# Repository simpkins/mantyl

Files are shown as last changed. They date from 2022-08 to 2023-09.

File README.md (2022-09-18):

# Mantyl: concave split keyboard

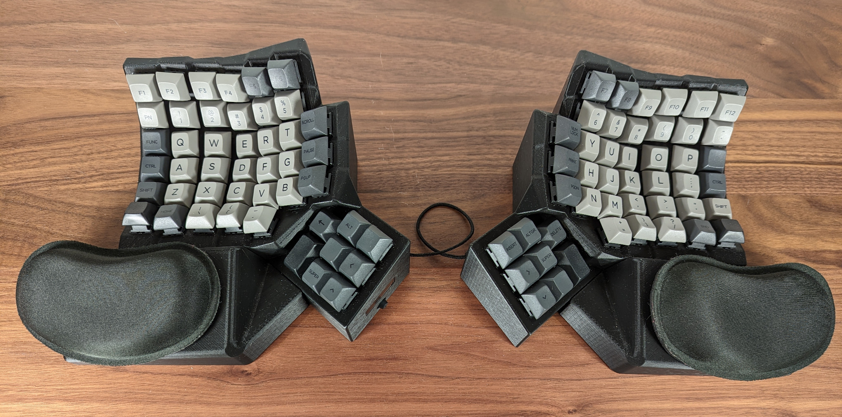
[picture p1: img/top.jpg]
Keyboard Image


This repository contains the CAD design code and firmware for my custom
keyboard.

# Keyboard Model

The `cad` directory contains code for generating the keyboard model, using
Python scripts for [Blender](https://www.blender.org/).

# Firmware

The `src` directory contains the firmware for the keyboard.  I use a
[FeatherS3](https://esp32s3.com/feathers3.html) for the microcontroller,
and the firmware code is built with the
[ESP-IDF](https://github.com/espressif/esp-idf).

# Gallery

Some more images can be found in the [img](img) directory.

# Documentation

The [doc](doc) directory contains various documentation.  The
[assembly.md](doc/assembly.md) and [wiring.md](doc/wiring.md) files may be of
interest if you are looking to print and assemble your own version of the
keyboard.

# Inspiration

I've used [Maltron](https://www.maltron.com/) keyboards for quite a long time.
My original Maltron keyboard was a PS/2 model, and back in 2013 I built my own
[keyboard controller](https://github.com/simpkins/avrpp) for it using a
[Teensy++ 2.0](https://www.pjrc.com/store/teensypp.html) microcontroller, in
order to convert it to a USB keyboard.

The layout for this keyboard is heavily influenced by the Maltron layout--I
wanted it to be fairly similar since I've used the Maltron layout for so long.

For generating the keyboard model programmatically I took some inspiration from
the [Dactyl-Manuform](https://github.com/abstracthat/dactyl-manuform) keyboard.
I initially started out using OpenSCAD, but quickly found it fairly limiting
and switched to using Python APIs for blender.  For some choices of the
electronic components, particularly the SX1509, I relied on some of the
component selection from my co-worker Wez's
[Halfdeck](https://github.com/wez/halfdeck) keyboard.

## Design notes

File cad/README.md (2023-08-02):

# Running the Mesh Generation Code

This code requires Blender 3.4+.

## Generating STL Files

The `generate_stl.py` file will export STL files for all of the keyboard parts.
It will place them inside an `_out/` directory.

This script can be run from the command line as follows:

```
blender -b -P generate_stl.py
```

## Development

If you want to make changes to the CAD logic, using the `test.py` script is the
easiest way to do this.

You can start it from the command line as follows:

```
blender -P test.py
```

This will launch blender and run the code from
[`mantyl/testing.py`](mantyl/testing.py).  Whenever
any of the source code files are updated it will reload and re-run the code to
redisplay the generated objects.

This makes it easy to edit the Python source code and have blender
automatically redisplay changes each time you save any of the files.

The logic for monitoring source code changes is in
[`mantyl/auto_update.py`](mantyl/auto_update.py).

# Checking for Errors

Blender's boolean operators can occasionally generate bad geometry.  This
sometimes happens if the operation generates new vertices at the mesh
intersection points that are very close to existing vertices.  This can result
in faces that intersect, which may cause problems when attempting to slice the
model for 3D printing.

The easiest way to detect this problem is with Blender's
[3D Print Toolbox](https://docs.blender.org/manual/en/latest/addons/mesh/3d_print_toolbox.html).
Enable the toolbox in the Add-On preferences.  After enabling it, press `N` in
an 3D view area to show the sidebar, and a "3D-Print" tab will be available.
This tab has buttons to check for intersections, and can highlight intersecting
faces.

# Other Notes

## Units

My scripts are written with the units in millimeters.  Historically this was
because I initially developed the keyboard model in OpenSCAD rather than
Blender, which uses units in millimeters rather than meters.

However, using millimeters works nicely in practice for Blender too: this
avoids having to scale the units by 1000 when exporting to an STL file, as 3D
print software generally assumes the STL units are in millimeters, while
Blender emits the units as meters by default.

## OpenSCAD

I initially attempted to build the keyboard model using OpenSCAD.  However, it
unfortunately has many more problems than Blender with generating bad geometry
after performing hull, union, and difference operations on objects in arbitrary
locations.  These problems unfortunately typically don't manifest themselves
until after you generate an STL file and attempt to slice it for 3D printing.
With OpenSCAD it was also much harder to detect which faces / facets were
problematic.

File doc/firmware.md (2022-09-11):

The firmware requires the ESP-IDF to build.  During development I have been
using the latest github master branch, which is currently in beta for the v5.0
release.

# eFuse Settings

The `USB_PHY_SEL` eFuse needs to be burned in order to have the device behave
purely as a USB keyboard.  Without this setting when the chip powers on it
first enables the USB Serial/JTAG functionality, and will enumerate as a USB
serial device before it fully boots and changes configuration to a USB HID
device.  This behavior can be undesirable in many circumstances, so burning the
`USB_PHY_SEL` eFuse is recommended.  e.g., when plugged into the keyboard port
of USB KVM switches, some KVM switches will power cycle the port if anything
other than a keyboard is plugged in.

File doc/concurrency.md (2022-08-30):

Some notes on tasks and concurrency in the firmware:

# Tasks

- main task
  All I2C communication is performed from this task.  This handles reading key
  information from the SX1509 chips, and updating the SSD1306 display.

  We also call tud_hid_keyboard_report() from this task when a key is pressed.
  We perform all USB HID interrupt transfers from this task.

- USB task
  This task runs the TinyUSB `tud_task()`

  We perform all USB control transfers from this task.
  (Note that USB HID interrupt transfers are performed from the main task.)

# I2C Access

All I2C access is performed from the main task.

# USB Access

All HID transfers are performed from the main task.
All control transfers are performed from the USB task.

CDC transfers performed by the esp-idf `tusb_console` code may be performed
from any task, but are always done with a lock held.  Separate locks are used
for the in and out endpoints for receive and transmit operations.

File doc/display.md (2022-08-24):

Notes on the UI for the OLED display.

# Menu Tree

- Select Keymap
  - List of keymaps
- Edit Keymap
- Debug
  - Key presses
  - USB Events (e.g., suspend & resume)
- Settings
  - Set Owner contact info
  - Screensaver
    - Off
    - Clock
  - WiFi
    - SSID
    - Password
- Owner
  - Owner contact info
- System Info
  - Firmware Version
  - Build Date

# Edit Keymap Operation

- Step 1: Press a physical key
- Step 2: Define a key for it
  - Can either press another physical key, and we will use it's value from the
    default keymap.
  - Or select from a menu on the OLED.
- Step 3: Confirm
  - Either hit enter, or right on the directional switch.

The confirm option is to make menu selection easier.  Can press as physical key
to jump to that key in the menu, then navigate from there.

# Clock

Get time from NTP.  It would be nice if we could get this from the computer
over USB, but there is no standard interface for this, so we would need custom
drivers.  Using NTP over WiFi is more straightforward to configure.

The SSD1306 supports automatic scrolling, so we could use that in clock
screensaver mode.

# Idle timeout

- After some amount of time, dim the display
- After an additional time, turn the display off
- When a display button is pressed again, start back at the top of the menu

# Error Log

- When an error message is logged:
  - If the display is off, open it and enter log view mode
  - If the display is already on in another mode, show the error message
    over the bottom line temporarily

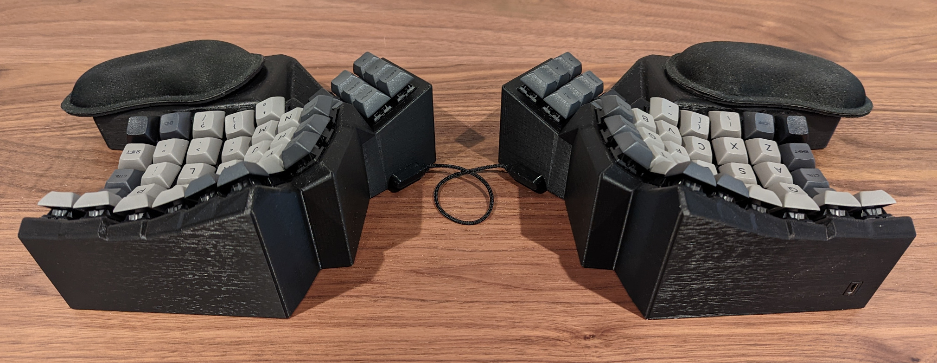
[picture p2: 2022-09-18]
img/back.jpg

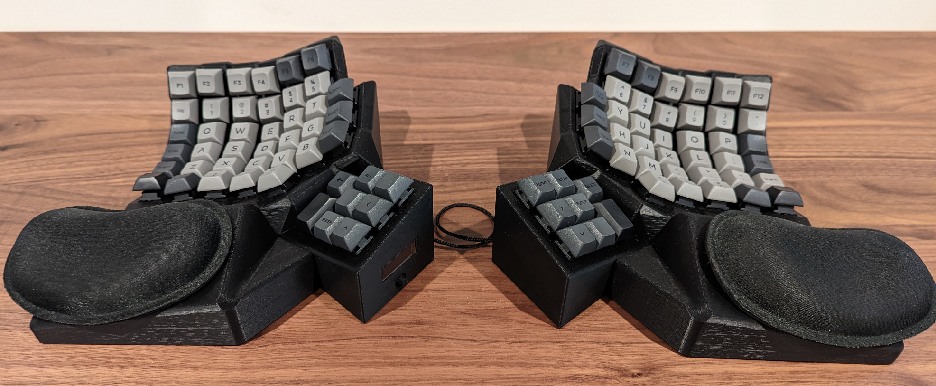
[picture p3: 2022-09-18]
img/front.jpg

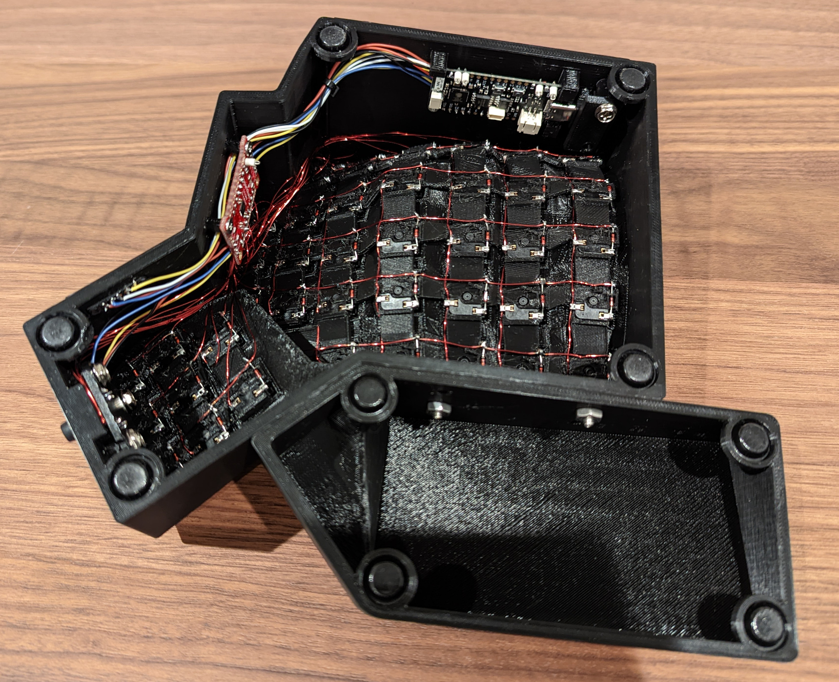
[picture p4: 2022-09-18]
img/left_interior.jpg

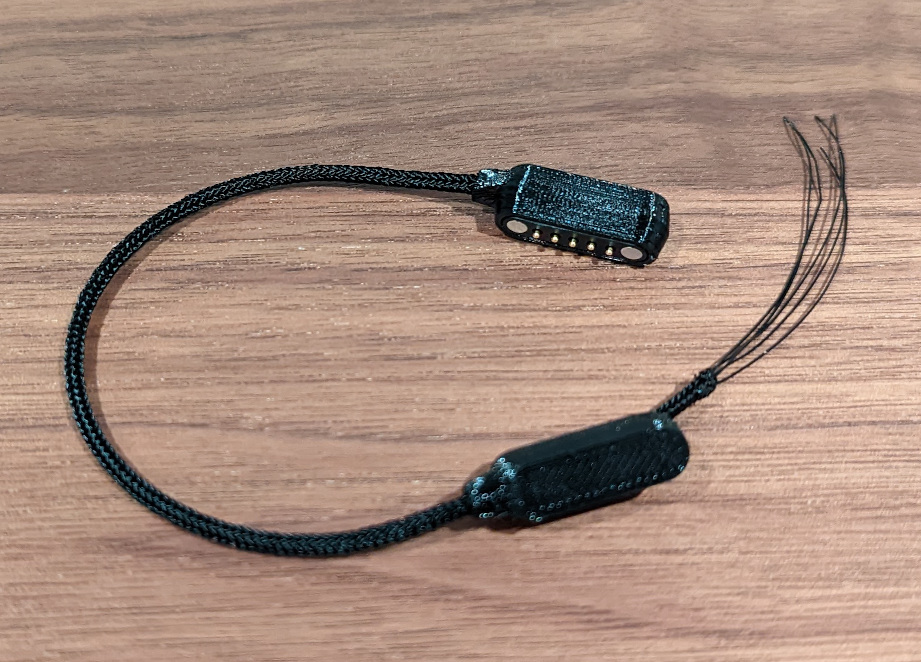
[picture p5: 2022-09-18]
img/cable_in_progress.jpg

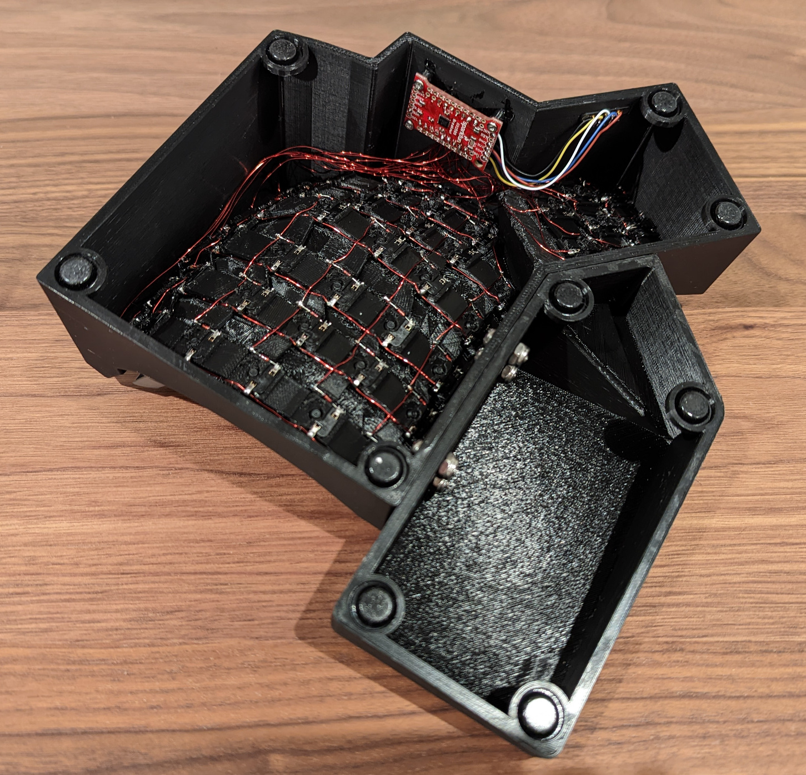
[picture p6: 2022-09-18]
img/right_interior.jpg

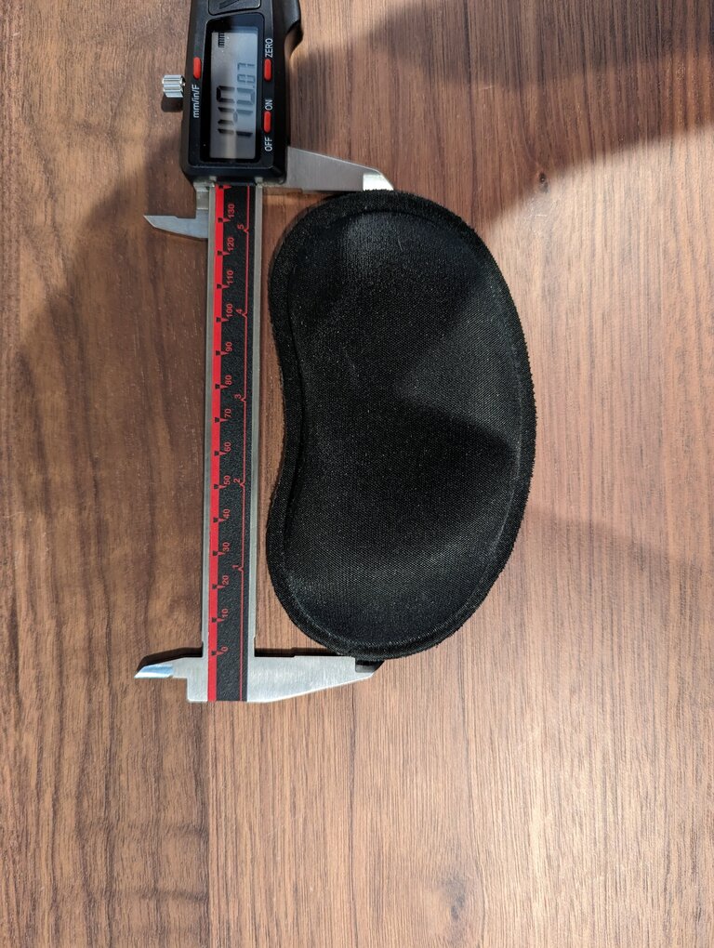
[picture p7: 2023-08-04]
cad/reference/wrist_rest.jpg

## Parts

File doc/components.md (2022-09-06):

* [FeatherS3](https://esp32s3.com/feathers3.html)

  The ESP32 supports USB, Wifi, and BLE.  This board is pretty beefy for a
  microcontroller--dual core processor, 8MB PSRAM, and 16MB flash.  It's
  overkill for this project, but still relatively inexpensive.

* [SX1509 I/O Expander Breakout](https://www.sparkfun.com/products/13601)
  Maybe in the future I'll print a PCB for this project where the SX1509
  can be incorporated directly on a board with the other components.  This
  breakout makes it very easy to use for now.

  [Arduino Library](https://github.com/sparkfun/SparkFun_SX1509_Arduino_Library)

* [128x32 I2C Monochrome OLED](https://www.adafruit.com/product/4440)

  [Arduino Library](https://github.com/adafruit/Adafruit_SSD1306)

* [5-pin magnetic connector](https://www.adafruit.com/product/5413)

  I used this connector for the cable between the two halves.  Having 5 pins
  allows me to also connect the SX1509 interrupt pin, in addition to I2C.

  Using a [TRRS Jack](https://www.sparkfun.com/products/12639) would also have
  been an option, and would allow using off-the-shelf audio cables, but would
  not allow connecting the interrupt pin.

  This [5-pin connector](https://www.adafruit.com/product/5317) is another
  option, but is a bit on the large and expensive side.

* [USB C right angle connector](https://www.amazon.com/AGVEE-Degree-Angled-Adapter-Converter/dp/B09FJTTZWY)

  I used this to expose the external USB-C socket.  This is a cheap connector I
  found on Amazon, and I have no idea if it will continue to be available in
  the future.  This connector is a perfect size for directly plugging it in to
  the FeatherS3 and exposing the port through the shell wall.

  I also considered using USB-C keystone jacks, but these would take up more
  space, and would require running a cable on the inside of the keyboard from
  the keystone jack to the FeatherS3.  Even a 6-inch cable is too long for
  this, and there are relatively few cables available that are shorter.

  Another option would be just using a plain
  [USB-C socket](https://www.adafruit.com/product/4396), and soldering half of
  a cable to it.  This would just require a little CAD rework to come up with a
  solution for securely fastening it to the keyboard shell.

* Pull-up resistors (x2)

  I am currently using 4.7kOhm resistors.

  The maximum allowed resistance is determined by the bus capacitance.  Since
  we do have a relatively long connection for an I2C bus, going too high could
  be problematic.  I haven't had problems with 4.7kOhm so far.

  The minimum resistance is determined by the amount of current needed to pull
  the bus line low.  Our signal level is 3.3V; the bus must be pulled lower
  than (3.3V * 0.3) to be recognized as low, or lower than 0.99V.  Pulling the
  bus to .99V across a 4.7kOhm resistor requires 0.5mA.  Pulling it all the way
  to 0V requires 0.7mA.

  The ESP32S3 GPIO pins have a maximum low-level sink current of 28mA, which
  gives us plenty of room.  The SX1509 has a maximum low-level sink current of
  8mA at 3.3V.  The SSD1306 datasheet unfortunately does not clearly list the
  maximum allowed voltage.  (It documents the maximum logic current as 150uA,
  but this seems like it might be for the SPI logic mode.)

* Diodes

  I am using 1N4148 diodes.  1N5817 should also work.

* Key switches

  Any cherry-compatible key switches should work.

* Screws

  * 8 #6-32 1/2" screws for connecting the wrist rests
  * 3 #6-32 1/4" screws for the LED backplate
  * 2 #6-32 1/4" screws for the USB connector backplate
  * 8 #2 1/4" screws for the SX1509 boards
  * 1 #2 1/4" screw for the FeatherS3

* Cable: Wire and Paracord

  For making the cable that connects the two halves, I used some very thin wire
  (34AWG wire), and threaded it through #95 paracord.  #275 paracord is just
  slightly larger, and would also be a reasonable choice.

  Wire: https://www.adafruit.com/product/4734

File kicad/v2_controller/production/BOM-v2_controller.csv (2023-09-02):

Comment | Designator | Footprint | LCSC
1k | R15 | R0402 | C11702
74AHCT1G125 | U3 | SOT-353_SC-70-5 | C151417
0 | R6,R7 | R0402 | C17168
1N5819WS | D18,D19 | SOD-323 | C191023
1N4148WS | D21,D22,D23,D24,D25,D26,D27,D28,D29,D30,D31,D32,D33,D34,D35,D36,D37 | SOD-323 | C2128
S8050 | Q1,Q2 | SOT-23 | C2150
Red LED | D20 | LED0603 | C2286
390k | R18 | R0603 | C23150
470 | R16 | R0402 | C25117
10k | R1,R17,R4,R5 | R0402 | C25744
22.1k | R13 | R0402 | C25768
47.5k | R14 | R0402 | C25792
4.7k | R2,R3 | R0402 | C25900
5.1k | R10,R11,R12,R8,R9 | R0402 | C25905
USBLC6-2P6 | U5,U6 | SOT-666 | C2827693
Conn_02x03_Odd_Even | J6 | PinSocket_2x03_P2.54mm_Vertical | C2829893
ESP32-S3-WROOM-1-N16R8 | U1 | ESP32-S3-WROOM-1 | C2913202
USB_C_Receptacle_USB2.0 | J1,J2 | GT-USB-7090x | C3019715
100nF | C10,C15,C16,C18,C19,C20,C21,C22,C23,C24,C25,C26,C27,C28,C29,C3,C30,C31,C32,C33,C34,C35,C36,C37,C38,C39 | C0402 | C307331
Boot | SW18,SW19 | SW_Push_1P1T_XKB_TS-1187A | C318884
Conn_02x10_Odd_Even | J3,J4 | IDC-Header_2x10_P2.54mm_Vertical | C3405
SK6812 Mini-E | D1,D10,D11,D12,D13,D14,D15,D16,D17,D2,D3,D38,D39,D4,D40,D41,D5,D6,D7,D8,D9 | SK6812-MINI-E | C5149201
KP0 | SW1,SW10,SW11,SW12,SW13,SW14,SW15,SW16,SW17,SW2,SW3,SW4,SW5,SW6,SW7,SW8,SW9 | Kailh_socket_MX_platemount | C5156480
1uF | C1,C11,C12,C4,C5,C8,C9 | C0402 | C52923
NCP167BMX330TBG | U4 | OnSemi_XDFN4-1EP_1.0x1.0mm_EP0.52x0.52mm | C892227
10uF | C17,C2,C6,C7 | C0603 | C96446
CP2102N-Axx-xQFN24 | U7 | QFN-24-1EP_4x4mm_P0.5mm_EP2.6x2.6mm | C969151

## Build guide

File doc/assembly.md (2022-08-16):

# Printing

I printed everything with PLA on a Prusa MK3S.

## Supports

Most of these parts have a lot of overhangs, and require supports.  I printed
breakaway supports, and was actually pleasantly surprised at how well this
worked, and that it was relatively straightforward to remove the supports
afterwards.

I sliced most of the models using Prusaslicer.  To make the supports easier to
remove, I printed with a 0.2mm Z contact distance for the supports, and a 100%
XY contact distance (as a function of the external perimeter width).  I used 2
top support interface layers, and 0 bottom interface layers.  I also expanded
the support pattern spacing to 3mm, just to reduce the amount of support
material printed.

I wasn't able to get Prusaslicer to avoid printing supports inside the screw
standoffs--even with support blockers, it still ends up generating supports
inside the screw hole if it needs to support something else above the screw
standoff.  In practice, this wasn't a big deal; the support material inside the
screw holes is not very much, and could be removed carefully with a drill bit.

## Underlays

Prusaslicer did not do a great job generating supports for the main underlays
that hold the switch sockets, so I sliced these using the Cura slicer.  It's
tree support functionality does a good job adding supports for this part, and
they broke away fairly easily, despite the fact that this part is somewhat thin
and fragile.

# Wiring

For wiring the keyboard, I used 28 gauge Soderon 155 from TEMCo.  This wire
does not need to be stripped prior to soldering, which saves time since there
are a lot of keys to solder.  It has a nylon insulation that will melt and act
as flux when soldering.  Note that it requires a minimum temperature of 390 C.

# Rows and Columns

The diodes can be installed in either direction, as long as you are consistent
throughout.

For my boards, I assembled the diodes with the anode connected to the switch,
and the cathode connected to the row wire.  I connected the rows to bank A of
the SX1509 (pins 0-7) and the columns to Bank B (pins 8-15).  Bank A therefore
needs to be configured as open drain, and bank B as pull-up.

See [wiring.md](wiring.md) for more notes on the connections to be made.

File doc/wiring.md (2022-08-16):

# Key Matrix

For the main underlay, simply wire the rows and columns straight across.
This uses 6 rows (R0-R5), and 7 columns (C0-C6).

Numbering the rows from top to bottom, and the columns from outward to inward
(so both sides are symmetrical), the only keys that are unused on the main
underlay are C6R0, C6R1, C5R5, and C6R5

Right thumb (viewed from the bottom):

       C6R0  C7R0
 C7R2
       C6R1  C7R1
 C5R5
       C6R5  C7R5

Left thumb (viewed from the bottom):

 C7R0  C6R0
             C7R2
 C7R1  C6R1
             C5R5
 C7R5  C6R5

For the directional switch below the display, use columns 0-4 on row 6.

# I2C Connection

From the outside of the keyboard to inside, the pins are:

  GND SCL INT SDA VCC

Having GND on the outside hopefully makes it a little more likely that it has
contact first before other pins when connecting/disconnecting, if it ever
happens to be pulled off while powered on.

# SX1509 Connections

Notes to record which wires get connected to each of the SX1509 pins:

## Pull-Ups

I installed the I2C pull-up resistors on the back side of the SX1509 boards.
The SX1509 have VC1 and VC2 through-holes that are connected to the 3V3 input
by default (with jumpers).  These through holes provide convenient locations to
install the resistors, and connect them to the SDA and SCL through-holes on
this board.

## Left

- 0
  - Row 0 from Main keypad
  - Row 0 from Thumb
- 1
  - Row 1 from Main keypad
  - Row 1 from Thumb
- 2
  - Row 2 from Main keypad
  - Row 2 from Thumb
- 3
  - Row 3 from Main keypad
- VC1
  - 4.7kOhm I2C SDA pull up
- 4
  - Row 4 from Main keypad
- 5
  - Row 5 from Main keypad
  - Row 5 from Thumb
- 6
  - Directional switch common pin
- 7

- 8
  - Column 0 from Main keypad
  - Directional switch 0
- 9
  - Column 1 from Main keypad
  - Directional switch 1
- 10
  - Column 2 from Main keypad
  - Directional switch 2
- 11
  - Column 3 from Main keypad
  - Directional switch 3
- VC2
  - 4.7kOhm I2C SCL pull up
- 12
  - Column 4 from Main keypad
  - Directional switch 4
- 13
  - Column 5 from Main keypad
  - Column 5 from Thumb
- 14
  - Column 6 from Main keypad
  - Column 6 from Thumb
- 15
  - Column 7 from Thumb

## Right

The right side is the same as the left, but without the directional switch.

# FeatherS3

- 10
  Right SX1509 INT
- 7
  Right I2C SCL
- 3
  Right I2C SDA
- 3
  Not connected (avoided since this is a strapping pin)
- 1
  Display RST
- 38
  Left SX1509 RST
- 33
  Left SX1509 INT
- 9 (SCL)
  Left I2C SCL
- 8 (SDA)
  Left I2C SDA

- 3V3.1
  Left VCC
- GND
  Ground
- 3V3.2
  Right VCC

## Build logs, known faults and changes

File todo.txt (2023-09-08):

# CAD

  - Numpad:
    - bottom cover
    - hat switch on front
    - figure out status LEDs
    - OLED display hole
    - controller screw standoffs
    - USB connector / hole

# Controller PCB

  - Re-do LEDs.
    - Each sk6812 uses 1mA even when off
    - Other LED driver alternatives:
      - IS31FL3733 / IS31FL3723
        - I2C
        - 12x16; 1 chip supports one RGBW led per key on each half
        - Various other matrix dimensions:
          IS31FL3741: 39x9
          IS31FL3743: 18x11
          IS31FL3737 / IS31FL3731: 12x12
      - Holtek makes some LED drivers:
        - HT1632: 24x16 or 32x8.  4-pin SMI
        - HT16K33: 16x8.  I2C.
          - also supports keyscan
      - Analog devices:
        - MAX6955: 16x8, I2C
          also supports keyscan but only some pins, only 32 keys
          seems quite expensive
        - MAX6954: 16x8, SPI
      - AS1130: 12x11 (charlieplexed with 12 pins)

    - RGBW LEDs:
      - HL-5050RGBW-S1
        Available cheaply from JLCPCB, but top mount.
        Might work on flex PCB would possibly require double sided build.
        Or perhaps attempt to manually mount sockets on back, and have some
        sort of stand-off around LED

      JLCPCB global sourcing parts:
        - Inolux IN-P32TRRRGB
          Also avilable from Digikey
        - SunLED XZMDKCBDDG45S-9
          Not in stock at JLCPCB, seems like they could order it cheaply.
          RGB rather than RGBW
        - Wurth Electronic 156120M173000
      Digikey / Mouser
        - IN-P32TRRRGB
          Cheaper than other options below.
          IN-S124TCRRGB is a reverse mount 1204 option
        - Osram LTRBRASF
          Available from Mouser, rather than JLCPCB.
          Expensive and would require manual assembly
        - QT Brightek QBLP677R-RGB
          Digikey
          Expensive and would require manual assembly
        - Kingbright AAA3528RBGS/08-09 
          Digikey
          Expensive and would require manual assembly

# Firmware

  - finish USB stack re-implementation
    - improved descriptors
    - remote wake-up
    - suspend handling
  - display UI

------------------------

# Low-pri

- V1 firmware:
  - Improve handling of right half disconnect

Low-pri future firmware:
  - Software-based USB serial download functionality
  - KeymapDB: save & load from flash

- docs:
  - Discuss burning the USB_PHY_SEL eFuse

- Low-pri future improvements:
  - custom flex PCB for left and right half keys
  - touchpad below right thumb?
    Azoteq TPS43-201A
  - headphone in + out jacks with volume potentiometer?
  - JTAG header

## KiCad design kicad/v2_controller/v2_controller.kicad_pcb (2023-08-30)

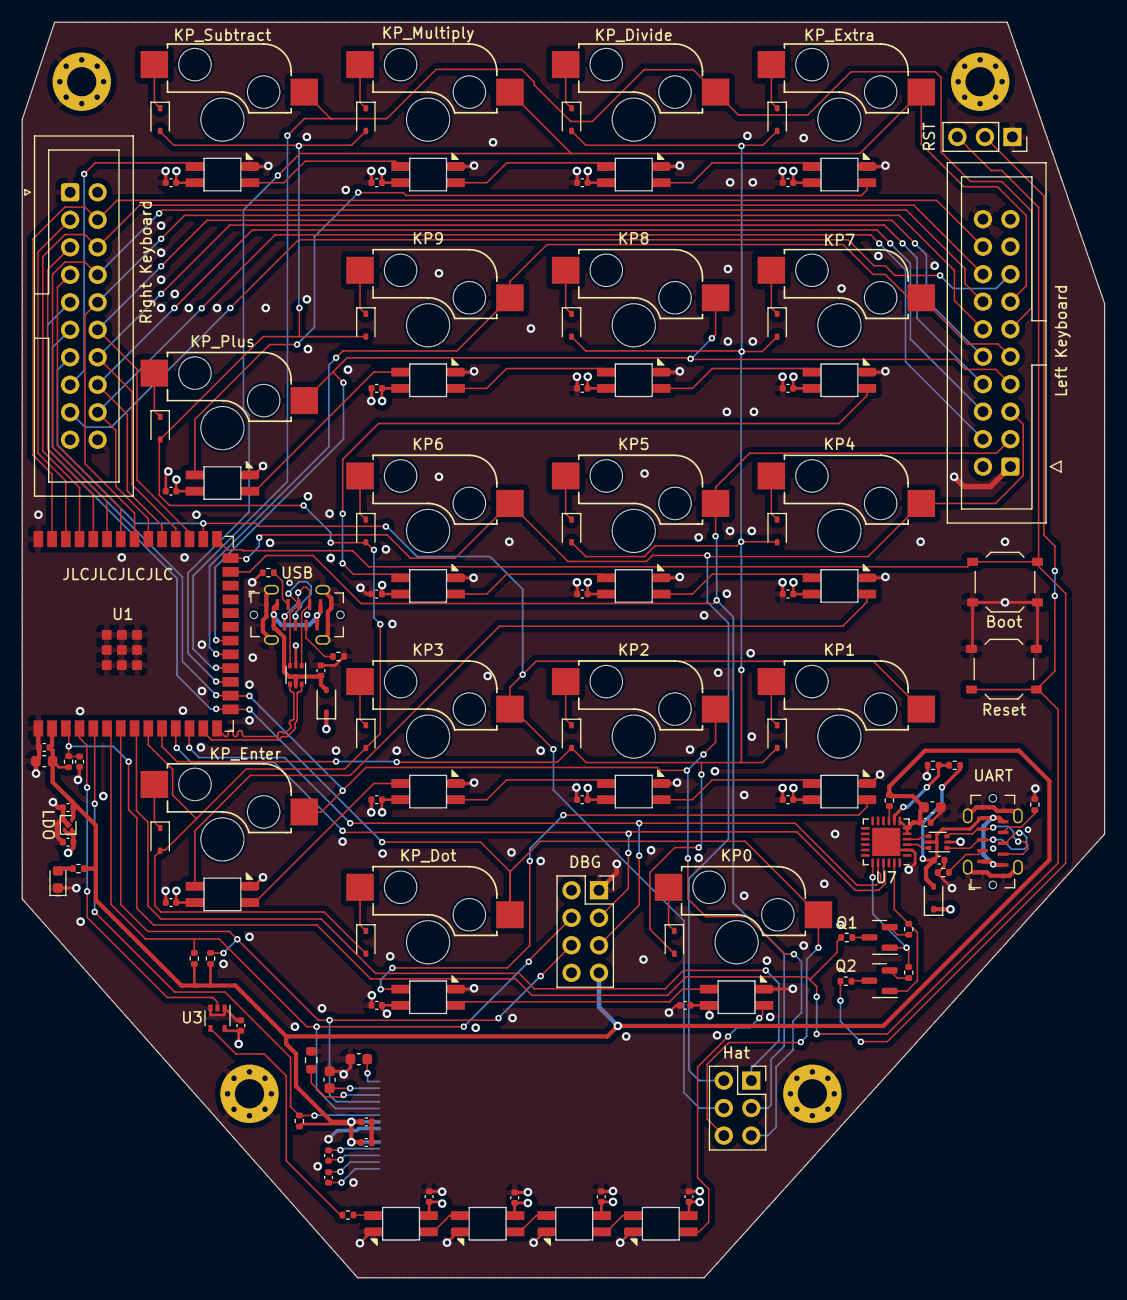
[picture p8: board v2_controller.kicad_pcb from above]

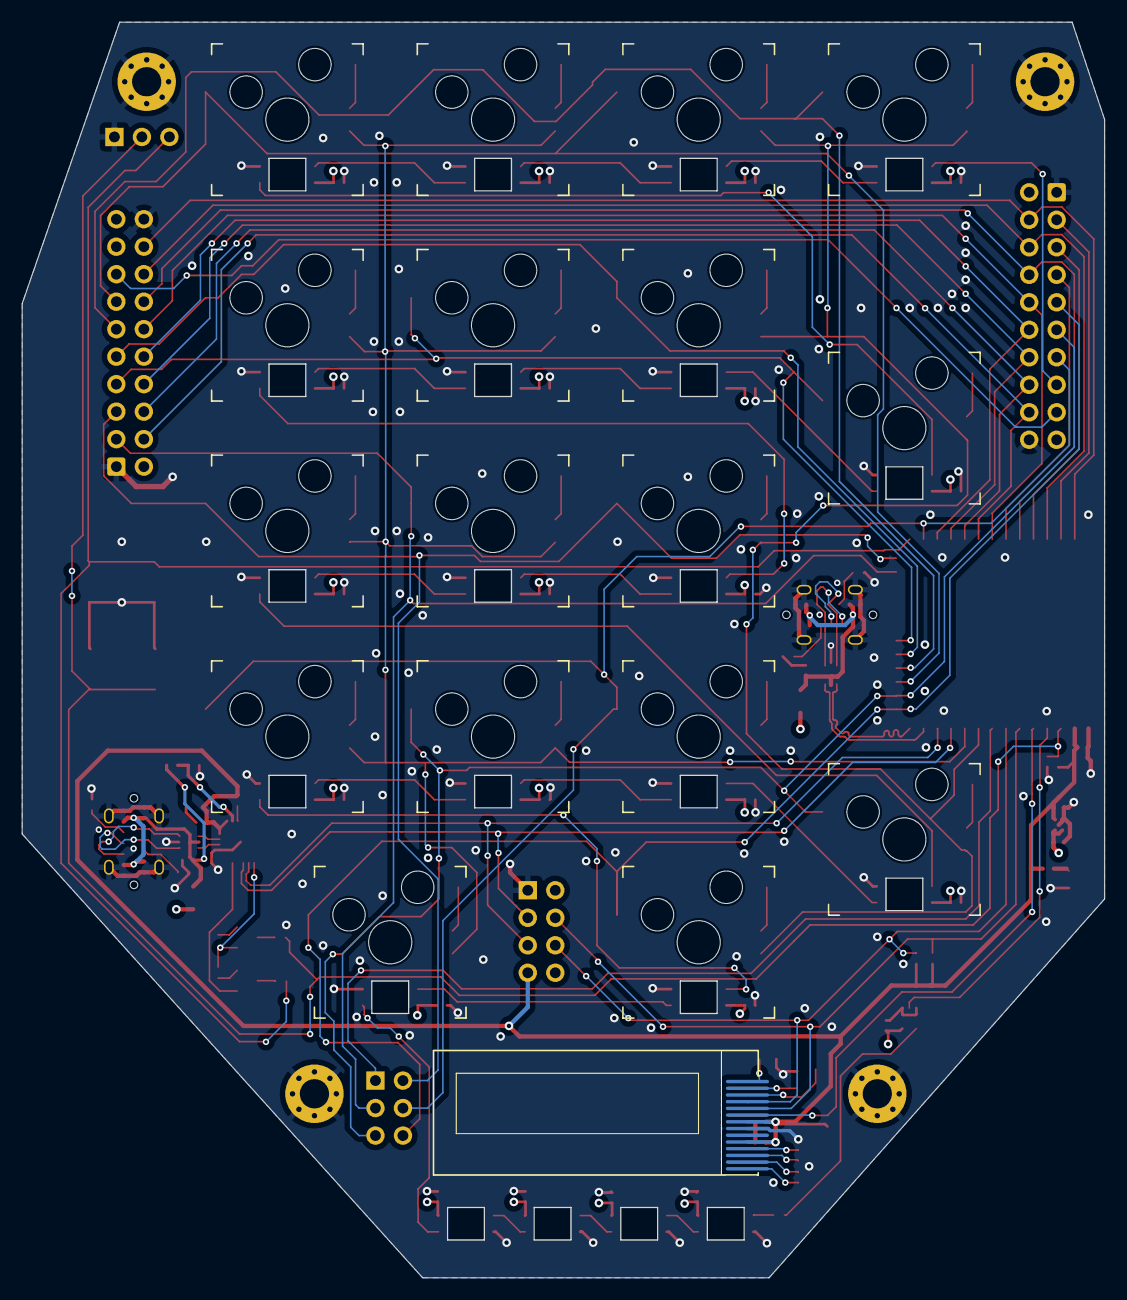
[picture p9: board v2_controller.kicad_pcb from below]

Board: 4 copper layers, 100.0 x 116.0 mm, 135 parts (18 on the bottom side), 105 nets.

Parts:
C1, C4, C5, C8, C9, C11, C12: 1uF; C_0402_1005Metric
C2, C6, C7, C17: 10uF; C_0603_1608Metric
C3, C10, C15, C16, C18, C19, C20, C21, C22, C23, C24, C25, C26, C27, C28, C29, C30, C31, C32, C33, C34, C35, C36, C37, C38, C39: 100nF; C_0402_1005Metric
D1, D2, D3, D4, D5, D6, D7, D8, D9, D10, D11, D12, D13, D14, D15, D16, D17, D38, D39, D40, D41: SK6812 Mini-E; SK6812-MINI-E
D18, D19: 1N5819WS; D_SOD-323
D20: Red LED; LED_0603_1608Metric
D21, D22, D23, D24, D25, D26, D27, D28, D29, D30, D31, D32, D33, D34, D35, D36, D37: 1N4148WS; D_SOD-323
H1, H2, H3, H4: MountingHole_Pad; MountingHole_2.7mm_M2.5_Pad_Via
J1, J2: USB_C_Receptacle_USB2.0; GT-USB-7090x
J3, J4: Conn_02x10_Odd_Even; IDC-Header_2x10_P2.54mm_Vertical
J5: Conn_02x04_Odd_Even; PinSocket_2x04_P2.54mm_Vertical
J6: Conn_02x03_Odd_Even; PinSocket_2x03_P2.54mm_Vertical
J7: Conn_01x03; PinSocket_1x03_P2.54mm_Vertical
Q1, Q2: S8050; SOT-23
R1, R4, R5, R17: 10k; R_0402_1005Metric
R2, R3: 4.7k; R_0402_1005Metric
R6, R7: 0; R_0402_1005Metric
R8, R9, R10, R11, R12: 5.1k; R_0402_1005Metric
R13: 22.1k; R_0402_1005Metric
R14: 47.5k; R_0402_1005Metric
R15: 1k; R_0402_1005Metric
R16: 470; R_0402_1005Metric
R18: 390k; R_0603_1608Metric
SW1: KP0; Kailh_socket_MX_platemount
SW2: KP_Dot; Kailh_socket_MX_platemount
SW3: KP1; Kailh_socket_MX_platemount
SW4: KP2; Kailh_socket_MX_platemount
SW5: KP3; Kailh_socket_MX_platemount
SW6: KP_Enter; Kailh_socket_MX_platemount
SW7: KP4; Kailh_socket_MX_platemount
SW8: KP5; Kailh_socket_MX_platemount
SW9: KP6; Kailh_socket_MX_platemount
SW10: KP7; Kailh_socket_MX_platemount
SW11: KP8; Kailh_socket_MX_platemount
SW12: KP9; Kailh_socket_MX_platemount
SW13: KP_Plus; Kailh_socket_MX_platemount
SW14: KP_Extra; Kailh_socket_MX_platemount
SW15: KP_Divide; Kailh_socket_MX_platemount
SW16: KP_Multiply; Kailh_socket_MX_platemount
SW17: KP_Subtract; Kailh_socket_MX_platemount
SW18: Boot; SW_Push_1P1T_XKB_TS-1187A
SW19: Reset; SW_Push_1P1T_XKB_TS-1187A
U1: ESP32-S3-WROOM-1-N16R8; ESP32-S3-WROOM-1
U2: SSD1306_I2C; SSD1306_OLED-0.91-128x32_Folded
U3: 74AHCT1G125; SOT-353_SC-70-5
U4: NCP167BMX330TBG; OnSemi_XDFN4-1EP_1.0x1.0mm_EP0.52x0.52mm
U5, U6: USBLC6-2P6; SOT-666
U7: CP2102N-Axx-xQFN24; QFN-24-1EP_4x4mm_P0.5mm_EP2.6x2.6mm

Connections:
+3.3V: C2.1, C3.1, C4.2, C5.2, C12.1, C17.2, C18.2, J5.7, R1.1, R2.1, R3.1, R12.2, R15.2, R17.1, U1.2 (3V3), U2.5 (VBAT), U2.8 (VDD), U4.1 (OUT), U7.5 (VIO), U7.6 (VDD), U7.7 (VREGIN)
+5V: C10.1, C11.1, C19.2, C20.2, C21.2, C22.2, C23.2, C24.2, C25.2, C26.2, C27.2, C28.2, C29.2, C30.2, C31.2, C32.2, C33.2, C34.2, C35.2, C36.2, C37.2, C38.2, C39.2, D1.1 (VDD), D2.1 (VDD), D3.1 (VDD), D4.1 (VDD), D5.1 (VDD), D6.1 (VDD), D7.1 (VDD), D8.1 (VDD), D9.1 (VDD), D10.1 (VDD), D11.1 (VDD), D12.1 (VDD), D13.1 (VDD), D14.1 (VDD), D15.1 (VDD), D16.1 (VDD), D17.1 (VDD), D18.1 (K), D19.1 (K), D38.1 (VDD), D39.1 (VDD), D40.1 (VDD), D41.1 (VDD), J3.2, J4.2, J5.2, U3.5 (VCC), U4.3 (EN), U4.4 (IN)
/ESP32/CHIP_PU: C1.1, J7.2, R1.2, R6.1, SW19.2, U1.3 (EN)
/ESP32/COL0: J3.18, J4.4, U1.39 (GPIO1)
/ESP32/COL1: J3.16, J4.6, U1.37 (GPIO43/U0TXD)
/ESP32/COL2: J3.14, J4.8, U1.35 (GPIO42)
/ESP32/COL3: J3.12, J4.10, U1.33 (GPIO40)
/ESP32/COL4: J3.10, J4.12, U1.29 (GPIO36)
/ESP32/COL5: J3.8, J4.14, U1.30 (GPIO37)
/ESP32/COL6: J3.6, J4.16, U1.31 (GPIO38)
/ESP32/COL7: J3.4, J4.18, U1.32 (GPIO39)
/ESP32/COL8: D21.2 (A), D23.2 (A), D24.2 (A), D27.2 (A), D28.2 (A), D30.2 (A), D31.2 (A), D34.2 (A), D35.2 (A), U1.10 (GPIO17/U1TXD)
/ESP32/COL9: D22.2 (A), D25.2 (A), D26.2 (A), D29.2 (A), D32.2 (A), D33.2 (A), D36.2 (A), D37.2 (A), U1.9 (GPIO16/XTAL_32K_N)
/ESP32/COL10: J6.1, U1.8 (GPIO15/XTAL_32K_P)
/ESP32/GPIO0: J7.3, R7.1, SW18.2, U1.27 (GPIO0/BOOT)
/ESP32/LED_DIN_3V3: U1.4 (GPIO4), U3.2
/ESP32/LED_LEFT_DIN: J3.15, J4.17
/ESP32/LED_NUMPAD_DIN: R16.1, U3.4
/ESP32/LED_RIGHT_DIN: D17.2 (DOUT), J4.15
/ESP32/OLED_RST: R17.2, U1.5 (GPIO5), U2.9 (RES#)
/ESP32/ROW0: J3.13, SW14.1, SW16.1, U1.17 (GPIO9)
/ESP32/ROW1: J3.11, SW15.1, SW17.1, U1.18 (GPIO10)
/ESP32/ROW2: J3.9, SW10.1, SW12.1, U1.19 (GPIO11)
/ESP32/ROW3: J3.7, SW11.1, SW13.1, U1.20 (GPIO12)
/ESP32/ROW4: J3.5, J6.2, SW7.1, SW9.1, U1.26 (GPIO45)
/ESP32/ROW5: J3.3, J6.3, SW8.1, U1.25 (GPIO48/SPICLK_N)
/ESP32/ROW6: J4.13, J6.4, SW3.1, SW5.1, U1.28 (GPIO35)
/ESP32/ROW7: J4.11, J6.5, SW4.1, SW6.1, U1.16 (GPIO46)
/ESP32/ROW8: J4.9, J6.6, SW1.1, SW2.1, U1.15 (GPIO3)
/ESP32/ROW9: J4.7, U1.34 (GPIO41)
/ESP32/ROW10: J4.5, U1.36 (GPIO44/U0RXD)
/ESP32/ROW11: J4.3, U1.38 (GPIO2)
/ESP32/SCL: J5.4, R2.2, U1.6 (GPIO6), U2.10 (SCL)
/ESP32/SDA: J5.6, R3.2, U1.7 (GPIO7), U2.11 (SDA)
/ESP32/UART_DTR: Q2.1 (E), R4.1, U7.23 (~DTR)
/ESP32/UART_RTS: Q1.1 (E), R5.1, U7.19 (~RTS)
/ESP32/UART_RX: J5.3, U1.11 (GPIO18/U1RXD), U7.21 (TXD)
/ESP32/UART_TX: J5.5, U1.12 (GPIO8), U7.20 (RXD)
/ESP32/USB_D+: U1.14 (GPIO20/USB_D+), U5.4 (I/O2)
/ESP32/USB_D-: U1.13 (GPIO19/USB_D-), U5.6 (I/O1)
/LEDs/LED_NP_MAIN_DIN: D1.4 (DIN), D41.2 (DOUT)
/USB/UART_USB_D+: U6.6 (I/O1), U7.3 (D+)
/USB/UART_USB_D-: U6.4 (I/O2), U7.4 (D-)
/USB/UART_USB_VBUS: C16.1, D19.2 (A), J2.A4 (VBUS), J2.A9 (VBUS), J2.B4 (VBUS), J2.B9 (VBUS), R13.1, U6.5 (VBUS)
/USB/USB_VBUS: C15.1, D18.2 (A), J1.A4 (VBUS), J1.A9 (VBUS), J1.B4 (VBUS), J1.B9 (VBUS), U5.5 (VBUS)
GND: C1.2, C2.2, C3.2, C4.1, C5.1, C6.2, C7.2, C10.2, C11.2, C12.2, C15.2, C16.2, C17.1, C18.1, C19.1, C20.1, C21.1, C22.1, C23.1, C24.1, C25.1, C26.1, C27.1, C28.1, C29.1, C30.1, C31.1, C32.1, C33.1, C34.1, C35.1, C36.1, C37.1, C38.1, C39.1, D1.3 (VSS), D2.3 (VSS), D3.3 (VSS), D4.3 (VSS), D5.3 (VSS), D6.3 (VSS), D7.3 (VSS), D8.3 (VSS), D9.3 (VSS), D10.3 (VSS), D11.3 (VSS), D12.3 (VSS), D13.3 (VSS), D14.3 (VSS), D15.3 (VSS), D16.3 (VSS), D17.3 (VSS), D20.1 (K), D38.3 (VSS), D39.3 (VSS), D40.3 (VSS), D41.3 (VSS), H1.1, H2.1, H3.1, H4.1, J1.A1 (GND), J1.A12 (GND), J1.B1 (GND), J1.B12 (GND), J1.S1 (SHIELD), J2.A1 (GND), J2.A12 (GND), J2.B1 (GND), J2.B12 (GND), J2.S1 (SHIELD), J3.1, J3.20, J4.1, J4.20, J5.1, J7.1, R8.2, R9.2, R10.2, R11.2, R14.2, R18.2, SW18.1, SW19.1, U1.1 (GND), U1.40 (GND), U1.41 (GND), U2.7 (VSS), U3.1, U3.3 (GND), U4.2 (GND), U4.5 (EPAD), U5.2 (GND), U6.2 (GND), U7.2 (GND), U7.25 (GND)
unnamed: D1.2 (DOUT), D2.4 (DIN)
unnamed: D2.2 (DOUT), D3.4 (DIN)
unnamed: D3.2 (DOUT), D4.4 (DIN)
unnamed: D4.2 (DOUT), D5.4 (DIN)
unnamed: D5.2 (DOUT), D6.4 (DIN)
unnamed: D6.2 (DOUT), D7.4 (DIN)
unnamed: D7.2 (DOUT), D8.4 (DIN)
unnamed: D8.2 (DOUT), D9.4 (DIN)
unnamed: D9.2 (DOUT), D10.4 (DIN)
unnamed: D10.2 (DOUT), D11.4 (DIN)
unnamed: D11.2 (DOUT), D12.4 (DIN)
unnamed: D12.2 (DOUT), D13.4 (DIN)
unnamed: D13.2 (DOUT), D14.4 (DIN)
unnamed: D14.2 (DOUT), D15.4 (DIN)
unnamed: D15.2 (DOUT), D16.4 (DIN)
unnamed: D16.2 (DOUT), D17.4 (DIN)
unnamed: D20.2 (A), R12.1
unnamed: D21.1 (K), SW1.2
unnamed: D22.1 (K), SW2.2
unnamed: D23.1 (K), SW3.2
unnamed: D24.1 (K), SW4.2
unnamed: D25.1 (K), SW5.2
unnamed: D26.1 (K), SW6.2
unnamed: D27.1 (K), SW7.2
unnamed: D28.1 (K), SW8.2
unnamed: D29.1 (K), SW9.2
unnamed: D30.1 (K), SW10.2
unnamed: D31.1 (K), SW11.2
unnamed: D32.1 (K), SW12.2
unnamed: D33.1 (K), SW13.2
unnamed: D34.1 (K), SW14.2
unnamed: D35.1 (K), SW15.2
unnamed: D36.1 (K), SW16.2
unnamed: D37.1 (K), SW17.2
unnamed: D38.4 (DIN), R16.2
unnamed: D38.2 (DOUT), D39.4 (DIN)
unnamed: D39.2 (DOUT), D40.4 (DIN)
unnamed: D40.2 (DOUT), D41.4 (DIN)
unnamed: J1.A5 (CC1), R8.1
unnamed: J1.B5 (CC2), R9.1
unnamed: J1.A6 (D+), J1.B6 (D+), U5.3 (I/O2)
unnamed: J1.A7 (D-), J1.B7 (D-), U5.1 (I/O1)
unnamed: J2.A5 (CC1), R10.1
unnamed: J2.B5 (CC2), R11.1
unnamed: J2.A6 (D+), J2.B6 (D+), U6.1 (I/O1)
unnamed: J2.A7 (D-), J2.B7 (D-), U6.3 (I/O2)
unnamed: Q1.2 (B), R4.2
unnamed: Q1.3 (C), R6.2
unnamed: Q2.2 (B), R5.2
unnamed: Q2.3 (C), R7.2
unnamed: C8.1, U2.4 (C1N)
unnamed: C8.2, U2.3 (C1P)
unnamed: C9.1, U2.2 (C2N)
unnamed: C9.2, U2.1 (C2P)
unnamed: R18.1, U2.12 (IREF)
unnamed: C6.1, U2.14 (VCC)
unnamed: C7.1, U2.13 (VCOMH)
unnamed: R13.2, R14.1, U7.8 (VBUS)
unnamed: R15.1, U7.9 (~RST)

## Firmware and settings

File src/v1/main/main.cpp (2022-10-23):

// Copyright (c) 2022, Adam Simpkins

#include "config.h"
#include "sdkconfig.h"

#include "App.h"

#include <esp_chip_info.h>
#include <esp_flash.h>
#include <esp_log.h>

#include <memory>

namespace {
const char *LogTag = "mantyl.main";
}

namespace mantyl {

void print_info() {
  /* Print chip information */
  esp_chip_info_t chip_info;
  uint32_t flash_size;
  esp_chip_info(&chip_info);
  ESP_LOGD(LogTag, "Running on %s chip with %d CPU core(s), WiFi%s%s, ",
           CONFIG_IDF_TARGET, chip_info.cores,
           (chip_info.features & CHIP_FEATURE_BT) ? "/BT" : "",
           (chip_info.features & CHIP_FEATURE_BLE) ? "/BLE" : "");

  ESP_LOGD(LogTag, "silicon revision %d, ", chip_info.revision);
  if (esp_flash_get_size(NULL, &flash_size) != ESP_OK) {
    ESP_LOGD(LogTag, "Get flash size failed");
    return;
  }

  ESP_LOGD(LogTag, "%luMB %s flash", flash_size / (1024 * 1024),
           (chip_info.features & CHIP_FEATURE_EMB_FLASH) ? "embedded"
                                                         : "external");

  ESP_LOGD(LogTag, "Minimum free heap size: %" PRIu32 " bytes",
           esp_get_minimum_free_heap_size());
}

} // namespace mantyl

extern "C" void app_main() {
  esp_log_level_set("mantyl.main", ESP_LOG_DEBUG);

  mantyl::print_info();

  // TODO: it would be nicer to make the App constructor constexpr,
  // and then declare App as a static constinit variable.
  auto app = std::make_unique<mantyl::App>();
  app->main();
  ESP_LOGW(LogTag, "main task exiting");
}

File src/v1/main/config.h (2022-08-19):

// Copyright (c) 2022, Adam Simpkins
#pragma once

#include <hal/i2c_types.h>

namespace mantyl {

enum : uint32_t {
  I2cClockSpeed = 400000,
};

enum PinConfig : int {
  LeftI2cSDA = 8,
  LeftI2cSCL = 9,
  RightI2cSDA = 7,
  RightI2cSCL = 10,
};

} // namespace mantyl

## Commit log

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2022-05-21 [cad] manually construct key grid, in an attempt to avoid OpenSCAD bugs
    OpenSCAD unfortunately generates buggy STL output. Generate the key
    grid manually to avoid OpenSCAD causing problems when unioning the
    connector hulls.
    This fixes all STL errors in the key grid, but unfortunately there are
    still other errors that prevent the full model from working properly.
2022-05-21 [cad] attempt to work around some buggy OpenSCAD hull behavior
    OpenSCAD generates garbage STL data when using this hull of 4 parts.
    Using the union of 2 hulls with 3 parts each generates slightly less
    broken STL (still has some bad normals, but at least no reversed facets
    any more).
2022-05-22 [cad] some minor tweaks to the key hole helper functions
    Checking in some code changes while I was testing and trying to get
    something where OpenSCAD's hull() function doesn't generate bad output.
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2022-05-22 [cad] revert some tweaks to the wall hull construction
    These changes did not really help avoid bugs in OpenSCAD's hull()
    behavior.
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2022-05-22 [cad] begin creating a new KeyGrid class with the newer logic
    Refactor the code to start a new implementation that avoids using
    OpenSCAD's hull() functionality as much as possible.
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2022-05-28 [cad] fix minor issue on the inside of the thumb wall
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2022-05-28 [cad] fix an issue at the thumb connecting wall
    The inner wall was intersecting the outer wall at this corner
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2022-05-28 [cad] fix some type checking errors
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2022-05-29 [cad] tweak some bevels to fix intersecting faces
    Blender generates intersecting faces at some of the bevels without these
    changes.
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2022-05-30 [cad][auto-update] move the menu options to the Edit menu
    Also fix a bug causing the monitored modules to be forgotten across
    cancellation and restart. This information needs to be global since
    we only notice new modules when they are first imported.
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2022-05-30 [cad][auto-update] revert back to a hand-maintained dependency list
    We need to correctly track the ordering between dependencies.
    Unfortunately the standard library's modulefinder utility does not work
    with numpy, so for now just revert back to a manually maintained list.
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2022-05-30 [cad] a couple minor typing fixes
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2022-05-31 [cad] fix some minor edge issues in the I2C connector cutout
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2022-06-05 [cad] fix a bug with import order in auto_update.py
    Also move info messages into auto_update.py
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2022-06-14 Restart after display initialization failure
    [App.cpp]
2022-06-17 [cad] work on socket holder grid
    This isn't quite working yet; the blender unions aren't quite doing
    what I want. I may need to update the generation logic to avoid unions,
    and manually construct more of the mesh.
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2022-06-19 [cad] clean up the socket holder base plate
    This avoids some slightly weird geometry that blender produces
    otherwise.
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2022-06-19 [cad] update socket holder connection code to work after transforms
    Detecting the top and bottom points on the faces previously did not work
    if a non-zero transform had been applied.
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2022-06-24 [cad] minor tweaks to the keyboard walls to make room for socket holders
    Add a little more room to the left wall to give more clearance for the
    socket holder grid.
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2022-06-28 [cad] simplify the key socket wire holders
    The features on the previous wire holders were too small to print well.
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2022-06-28 [cad] trim off additional edges around the underlay
    This is to make sure we have enough clearance between the underlay
    and the keyboard walls.
2022-06-28 [cad] provide a little more clearance for the underlay
    Adjust some of the keyboard walls to make more room for the switch legs
    and underlay. This allows the underlay to all be facing one direction,
    rather than having to place some key switches upside down near the
    walls.
2022-06-28 [cad] clean up the underlay
    Now that there is more clearance for the underlay, orient all switches
    facing the same direction.
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2022-06-29 [cad] fix a big in auto_update.py if some modules were never imported
    Don't throw an exception if some of the watched modules were never
    imported in the first place.
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2022-07-02 [cad] fix some intersecting faces in the keyboard shell
    These were introduced when adding more clearance for the underlay.
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2022-07-09 [cad] rework the OLED display cutout
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2022-07-15 [cad] add a screw standoff on the flipped USB cutout
2022-07-16 [cad] clean up one minor issue with the usb cutout screw hole
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2022-08-14 [firmware] use a separate I2C bus for the right half
    This should the likelihood of any issues with the connection to the
    right half causing problems for the i2c devices in the left half.
    This also makes it easier to independently reset the two halves.
    This may also make it easier to detect the right half being connected or
    disconnected if I put the pull-up resistors for the right I2C bus inside
    the right half of the keyboard. I should be able to detect the right
    half being plugged in when SDA and SCL are pulled up in this case.
    [main.cpp]
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2022-08-19 [firmware] fix right half i2c configuration
    [config.h, main.cpp]
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2022-08-27 [firmware] add a delay to fix USB initialization
    For some reason, calling tusb_init() immediately after usb_new_phy()
    does not seem to successfully reset the device. A delay is required
    between these operations in order for the device to be reset and
    re-registered with the USB host.
    [App.cpp]
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2022-08-30 [firmware] add a todo comment about handling HID report errors
    [Keyboard.cpp]
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2022-08-30 [firmware] correctly handle HID report send failures
    [Keyboard.cpp]
2022-09-01 [firmware] janky workaround to TinyUSB race conditions
    Add a check to tud_hid_ready() before attempting to send a HID report.
    This check is racy, but is better than nothing. The
    tud_hid_keyboard_report() code crashes if called when the device is not
    mounted. It is unfortunately unsafe to call from anywhere other than
    the TinyUSB task, and the TinyUSB task is unusable for other work on
    FreeRTOS systems.
    [Keyboard.cpp]
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2022-09-02 [cad] adjust the phase of rotation on the feet to avoid errors
    Adjust the rotation a bit so that blender no longer generates
    intersecting faces when applying the boolean union operators.
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2022-09-18 [cad] raise keyboard by 1mm
    Decrease the recess for the feet by 1mm, to increase the clearance
    off the ground.
2022-09-18 [doc] update the cad/README.md file
    Also fix some minor errors when using the left.py and right.py top-level
    scripts.
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2022-10-23 [firmware] start working on a custom USB device implementation
    This is some new code for directly implementing a USB device stack,
    without using TinyUSB. TinyUSB's synchronization model does not really
    seem correct on FreeRTOS. For proper synchronization it seems all
    interaction with the USB state should be done from the task running
    tud_task(). The current TinyUSB behavior does not really make it easy
    to run other custom logic on this task. While I could try getting this
    fixed upstream, I figured I might as well take a stab at just directly
    implementing a USB stack. I already have code I had implemented in the
    past for HID keyboard devices on Atmel microcontrollers. This diff
    starts i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
    [App.cpp, App.h, Esp32UsbDevice.cpp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]
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2022-10-23 [firmware] add a device argument to the Esp32UsbDevice constructor
    This probably doesn't really matter since the esp32s2 and esp32s3 chips
    only support a single USB device. It seems like we might as well allow
    specifying this as a parameter though, on the off chance that there is a
    chip in the future with multiple USB devices.
    Also make the constructor constexpr.
    [Esp32UsbDevice.cpp, Esp32UsbDevice.h]
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2022-11-14 [usb] fix some bugs in the static descriptor construction logic
    [main.cpp]
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2023-06-13 [cad] fix typing errors in auto_update.py
2023-06-13 [cad] fix type errors in blender_util.py and cad.py
    Most of these are due to the fact that the annotations in the
    blender-stubs package are inaccurate/incomplete. I generally just added
    pyre-fixme for these issues.
2023-06-13 [cad] continue fixing more typing errors
2023-06-13 [cad] fix type errors in key_socket_holder.py
2023-06-13 [cad] fix type errors in numpad.py
2023-06-13 [cad] fix all remaining typing errors in non-strict pyre mode
2023-06-13 [cad] enable pyre strict mode
    This addresses all but one error, about our use of __getattr__
    to allow easy access to specific keys. I plan to improve the type
    annotation to handle that correctly in a subsequent diff.
2023-06-13 [cad] address remaining pyre-strict errors
2023-08-02 Split generic blender cad utilities to a separate package
    Also improve the auto_update.py code to no longer need the module
    dependency order to be manually specified.
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2023-08-03 [cad] fix gap in numpad surface, and show possible oled display
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2023-08-03 [cad] fix typing errors
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2023-08-03 [cad] fix some edges in the numpad mesh
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2023-08-05 [cad] more work on a redesigned wrist rest
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2023-08-08 [cad] fix a minor issue in kbd_halves.py
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2023-08-11 Add kicad project for number pad layout
    [v2_key_matrix.kicad_pcb, v2_key_matrix.kicad_sch]
2023-08-11 [kicad] rename and update numpad kicad project
    [v2_key_matrix.kicad_pcb, v2_numpad.kicad_pcb, v2_numpad.kicad_sch]
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2023-08-11 [kicad] start working on kicad project for v2 controller board
    [v2_controller.kicad_pcb, v2_controller.kicad_sch]
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2023-08-11 [kicad] update schematic for v2 controller
    [v2_controller.kicad_pcb, v2_controller.kicad_sch]
2023-08-12 [kicad] save updates to v2 controller
    [v2_controller.kicad_pcb]
2023-08-12 [kicad] numpad work in progress
    [esp32.kicad_sch, numpad.kicad_sch, v2_numpad.kicad_sch]
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2023-08-13 [cad] fix pyre after moving bpycad to a submodule
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2023-08-14 [kicad] some more minor tweaks to the numpad
    [esp32.kicad_sch, v2_numpad.kicad_sch]
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2023-08-15 [kicad] add template for ESP32-S3 boards
    Includes CP2102N, 3.3V regulator, USB connectors, power LED, and
    boot/reset switches.
    [esp32.kicad_sch, esp32s3.kicad_pcb, esp32s3.kicad_sch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]
2023-08-15 [kicad] check in schematic from v2_numpad missed in previous commits
    [cp2102n.kicad_sch]
2023-08-15 [kicad] update annotations in esp32s3 template
    [usb.kicad_sch]
2023-08-15 [kicad] remove older v2 projects
    [cp2102n.kicad_sch, esp32.kicad_sch, numpad.kicad_sch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]
2023-08-16 [kicad] begin working on a new v2 controller board
    [esp32.kicad_sch, keys.kicad_sch, leds.kicad_sch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]
2023-08-16 [kicad] additional work on v2 controller
    [esp32.kicad_sch, keys.kicad_sch, leds.kicad_sch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]
2023-08-16 [kicad] add status LEDs to the v2 controller
    [leds.kicad_sch]
2023-08-16 [kicad] fix global symbol usage in v2 controller
    [esp32.kicad_sch, keys.kicad_sch, leds.kicad_sch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]
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2023-08-16 [kicad] update v2 controller to use hierarchical labels
    [esp32.kicad_sch, keys.kicad_sch, leds.kicad_sch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]
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2023-08-17 [cad] fix pyre typing issues
2023-08-17 [cad] fix up the front left inside corner of the wrist rest
    This cleans up the mesh and flattens the inside walls near the screw
    holes.
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2023-08-17 [kicad] add a debug header to the v2 controller
    [esp32.kicad_sch, usb.kicad_sch]
2023-08-17 [kicad] add pcb board outline
    [v2_controller.kicad_pcb]
2023-08-17 [kicad] work on PCB layout
    [v2_controller.kicad_pcb]
2023-08-17 [kicad] renumber key diodes, and clean up column wiring
    [keys.kicad_sch]
2023-08-17 [kicad] more work on v2 controller PCB layout
    [v2_controller.kicad_pcb]
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2023-08-17 [kicad] more v2 controller work
    Update the switch symbols to single pole, since the XKB TS-1187A
    footprint only uses 2 pins, even though it has 4 pads.
    Also tweak the positioning of the ESP32-S3-WROOM and the board edge,
    so that the antenna is off the board.
    [esp32.kicad_sch, keys.kicad_sch, v2_controller.kicad_pcb]
2023-08-17 [kicad] use vertical USB-C receptacles
    There isn't enough space around the edges of the board for horizontal
    mount receptacles.
    [usb.kicad_sch, v2_controller.kicad_pcb]
2023-08-18 [kicad] more v2 controller PCB tweaks
    [v2_controller.kicad_pcb]
2023-08-18 [kicad] hide most capacitor and diode labels on the silkscreen
    [v2_controller.kicad_pcb]
2023-08-18 [kicad] swap LDO from AMS1117 to NXP167BMX330TBG
    I originally used AMS1117 since it is available as a basic part from
    JLCPCB. However, it requires a 22uF tantalum capacitor on the output,
    which is only available as extended part, negating the cost savings of
    the basic part.
    This switches to using the NXP167BMX330TBG chip instead, which has much
    lower quiescent current draw, higher PSRR, and a smaller footprint. It
    is only rated for 700mA, compared to 1A for the AMS1117, but my board
    generally shouldn't be drawing that much power through the 3.3V lines.
    The maximum allowed current draw for USB 2.0 is only 500mA. The LEDs
    are also probably the highest current draw, and these are powered
    di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
    [usb.kicad_sch]
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2023-08-18 [kicad] finish initial component placement
    This will probably need to be tweaked further once I begin routing,
    but is a start for now.
    [esp32.kicad_sch, leds.kicad_sch, oled.kicad_sch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]
2023-08-18 [kicad] move the main USB receptacle closer to the ESP32
    [v2_controller.kicad_pcb]
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2023-08-18 [kicad] tweak the pcb layout with a slightly larger board
    [v2_controller.kicad_pcb]
2023-08-18 [kicad] more minor tweaks
    [leds.kicad_sch, v2_controller.kicad_pcb]
2023-08-18 [kicad] switch USB receptacles again, and other PCB improvements
    Switch the USB receptacles to GT-USB-7090B, since the GT-USB-7051A had
    very limited space for routing traces.
    Also add labels on the key switches, and check in 3d models for more
    components.
    [keys.kicad_sch, usb.kicad_sch, v2_controller.kicad_pcb]
2023-08-19 [kicad] begin routing some traces
    [esp32.kicad_sch, usb.kicad_sch, v2_controller.kicad_pcb]
2023-08-19 [kicad] a little more trace routing
    [esp32.kicad_sch, v2_controller.kicad_pcb]
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2023-08-19 [kicad] largely finish routing except for ground and 5V planes
    [v2_controller.kicad_pcb]
2023-08-19 [cad] write some code to help verify PCB layout locations
    [v2_controller.kicad_pcb]
2023-08-19 [kicad] fix key locations
    The key locations were previously off by 1mm in the Y axis.
    [v2_controller.kicad_pcb]
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2023-08-20 [kicad] update part numbers for headers
    [esp32.kicad_sch]
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2023-08-22 [kicad] add ground and power planes, and finish connections
    [v2_controller.kicad_pcb]
2023-08-22 [kicad] clean up most PCB DRC violation issues
    [v2_controller.kicad_pcb]
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2023-08-27 [kicad] clean up additional PCB issues
    [usb.kicad_sch, v2_controller.kicad_pcb]
2023-08-27 [kicad] center the OLED display
    Also make other minor tweaks to clean up trace placement.
    [v2_controller.kicad_pcb]
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2023-08-29 [kicad] switch OLED to mount on the back, folding the FPC connector
    [oled.kicad_sch, v2_controller.kicad_pcb]
2023-08-30 [kicad] re-center the OLED, and add more ground vias
    [v2_controller.kicad_pcb]
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2023-08-30 [kicad] add a header for an external reset button
    [esp32.kicad_sch, v2_controller.kicad_pcb]
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2023-08-30 [kicad] some additional detail tweaks
    - Mark the OLED as not populated (I will manually attach this on the
    bottom of the board).
    - Clean up the F.Fab layer
    - Add teardrops
    [oled.kicad_sch]
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2023-08-31 [kicad] correctly list SK6812MINI-E as an SMD part
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2023-08-31 [kicad] add JLCPCB offset for the ESP32 module
    [esp32.kicad_sch]
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2023-08-31 [kicad] add JLCPCB position offset for switch sockets
    [keys.kicad_sch]
2023-08-31 [kicad] update JLCPCB socket offset to reflect flipped position
    I'm using this socket flipped, so I had previously incorrectly
    set the X axis up negative from what the value needed to be.
    [esp32.kicad_sch, keys.kicad_sch]
2023-08-31 [kicad] update USB connector symbols to have 14 pins
    The USB connectors I am using have 14 pins rather than 16, so update
    the symbol in the schematic to also have 14 pins. This prevents Kicad
    from complaining about these 2 extra pins when updating the PCB from the
    schematic, even though they are not connected in the schematic.
    [usb.kicad_sch]
2023-08-31 [kicad] update todo to remove offsets that have been fixed
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2023-09-01 [kicad] fix Kailh socket footprint to use F_Cu as the primary layer
    Kicad assumes all footprints are on the top side. The Kailh footprint
    was previously using the bottom side as its primary side, which caused
    the position export to generate the wrong side.
2023-09-01 [kicad] fix incorrect JLCPCB part number for R1
    [esp32.kicad_sch]
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2023-09-05 [cad] improve the keyboard feet
    Avoid having acute internal angles between the foot pads and the wall.
    This looks nicer and will make it easier to have an cover plate for the
    bottom.
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2023-09-06 [cad] work on a print for testing cover tolerances
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2023-09-07 [cad] fix pyre annotation issues in cover.py
2023-09-07 [cad] fix typing errors in foot.py
2023-09-07 [cad] fix additional type annotation issues
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
